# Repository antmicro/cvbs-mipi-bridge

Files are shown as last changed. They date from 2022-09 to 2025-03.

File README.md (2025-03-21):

# Composite Video (CVBS) to MIPI CSI-2 bridge

Copyright (c) 2022-2025 [Antmicro](https://www.antmicro.com)



Baseboard visualization

## Overview

This repository contains open hardware design files for a video bridge converting the analog composite video (CBVS) standard into MIPI CSI-2.
The video conversion is handled with Analog Devices [ADV7828-M](https://www.analog.com/media/en/technical-documentation/data-sheets/ADV7282.pdf) 10-bit 4x Oversampled SDTV Video Decoder.
The design files were prepared in KiCad.

## Repository structure

The main repository directory contains KiCad PCB project files, a LICENSE and README.
The remaining files are stored in the following directories:

* `lib` - contains the component libraries
* `img` - contains graphics for this README
* `doc` - contains pdf schematics
* `assets` - contains visual assets for showcasing this design on [Open Hardware Portal](https://openhardware.antmicro.com)

## Key Features

* Analog Devices ADV7282-M CVBS-to-MIPI video converter
* 4 analog video input channels exposed on RCA connectors
* A single 1-lane MIPI CSI-2 digital output interface

Please note that according to the datasheet the ADV7282-M includes an embedded analog multiplexer and processes only one analog input channel at a time.

This video accessory is electrically compatible with several video processing platforms created by Antmicro, such as:
 
* [Jetson Nano Baseboard](https://github.com/antmicro/jetson-nano-baseboard) supporting NVIDIA Jetson Nano, Jetson Xavier NX, Jetson TX2 NX
* [Google Coral Baseboard](https://github.com/antmicro/google-coral-baseboard)
* [Snapdragon 625 Baseboard](https://github.com/antmicro/snapdragon-625-baseboard)
* [Snapdragon 845 Baseboard](https://github.com/antmicro/snapdragon-845-baseboard)
* [AMD-Xilinx Kria K26 DevBoard](https://github.com/antmicro/kria-k26-devboard)

It can also be used with NVIDIA AGX Xavier and NVIDIA AGX Orin with a dedicated [adapter](https://github.com/antmicro/jetson-agx-csi-adapter).

## Board diagram

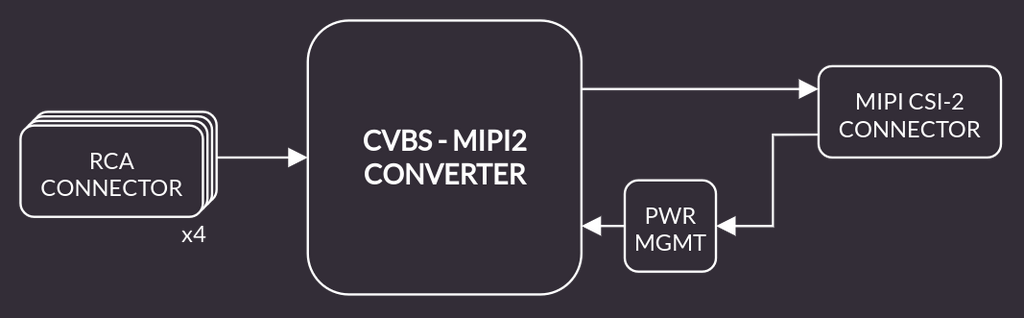
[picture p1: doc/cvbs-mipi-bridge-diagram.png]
Diagram


## License

[Apache-2.0](LICENSE)

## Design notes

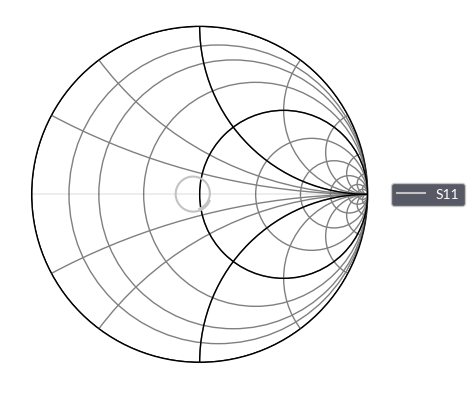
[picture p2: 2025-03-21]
assets/si/AIN1_ESD/S_11_smith.png

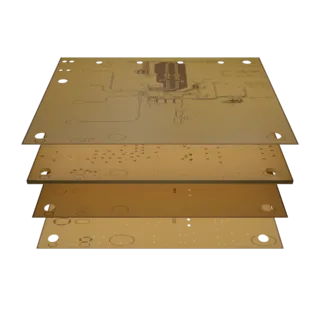
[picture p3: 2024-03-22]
assets/previews/layer1_thumbnail.webp

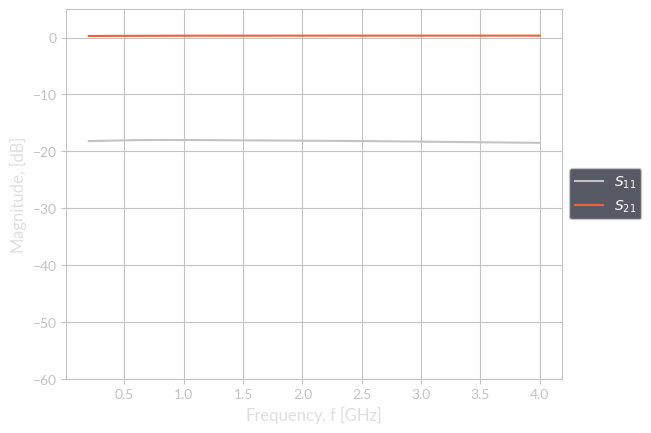
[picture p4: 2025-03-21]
assets/si/AIN2/S_x1.png

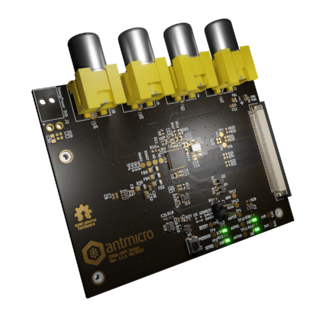
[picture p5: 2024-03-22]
assets/previews/leftT_thumbnail.png

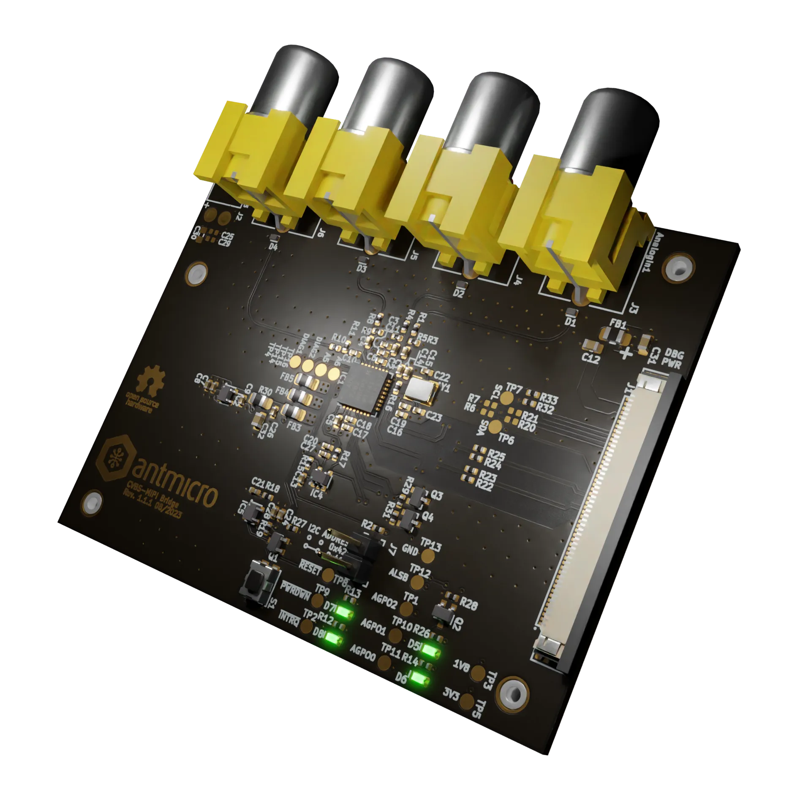
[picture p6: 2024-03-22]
assets/previews/rightT.webp

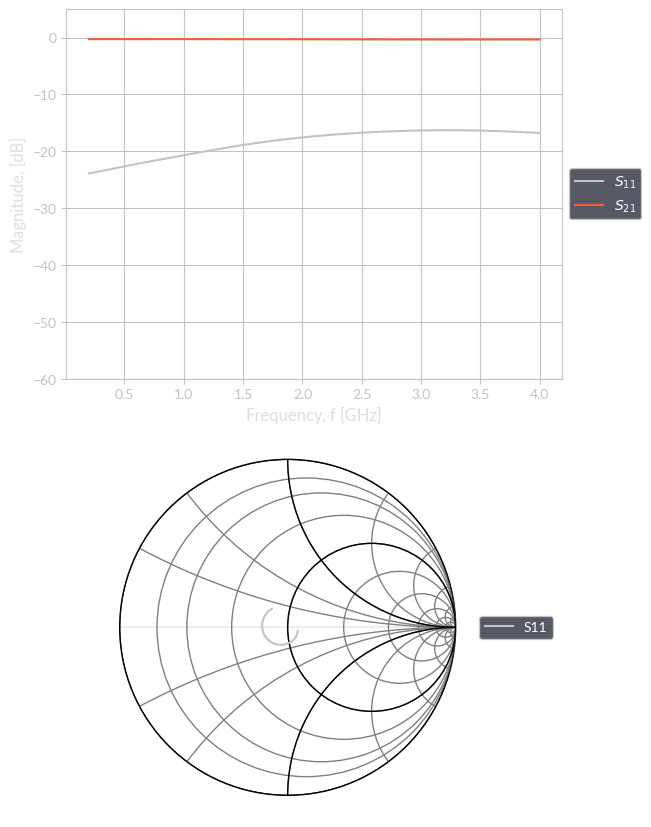
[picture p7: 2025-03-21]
assets/si/AIN2_ESD/s_param_and_smith_1.png

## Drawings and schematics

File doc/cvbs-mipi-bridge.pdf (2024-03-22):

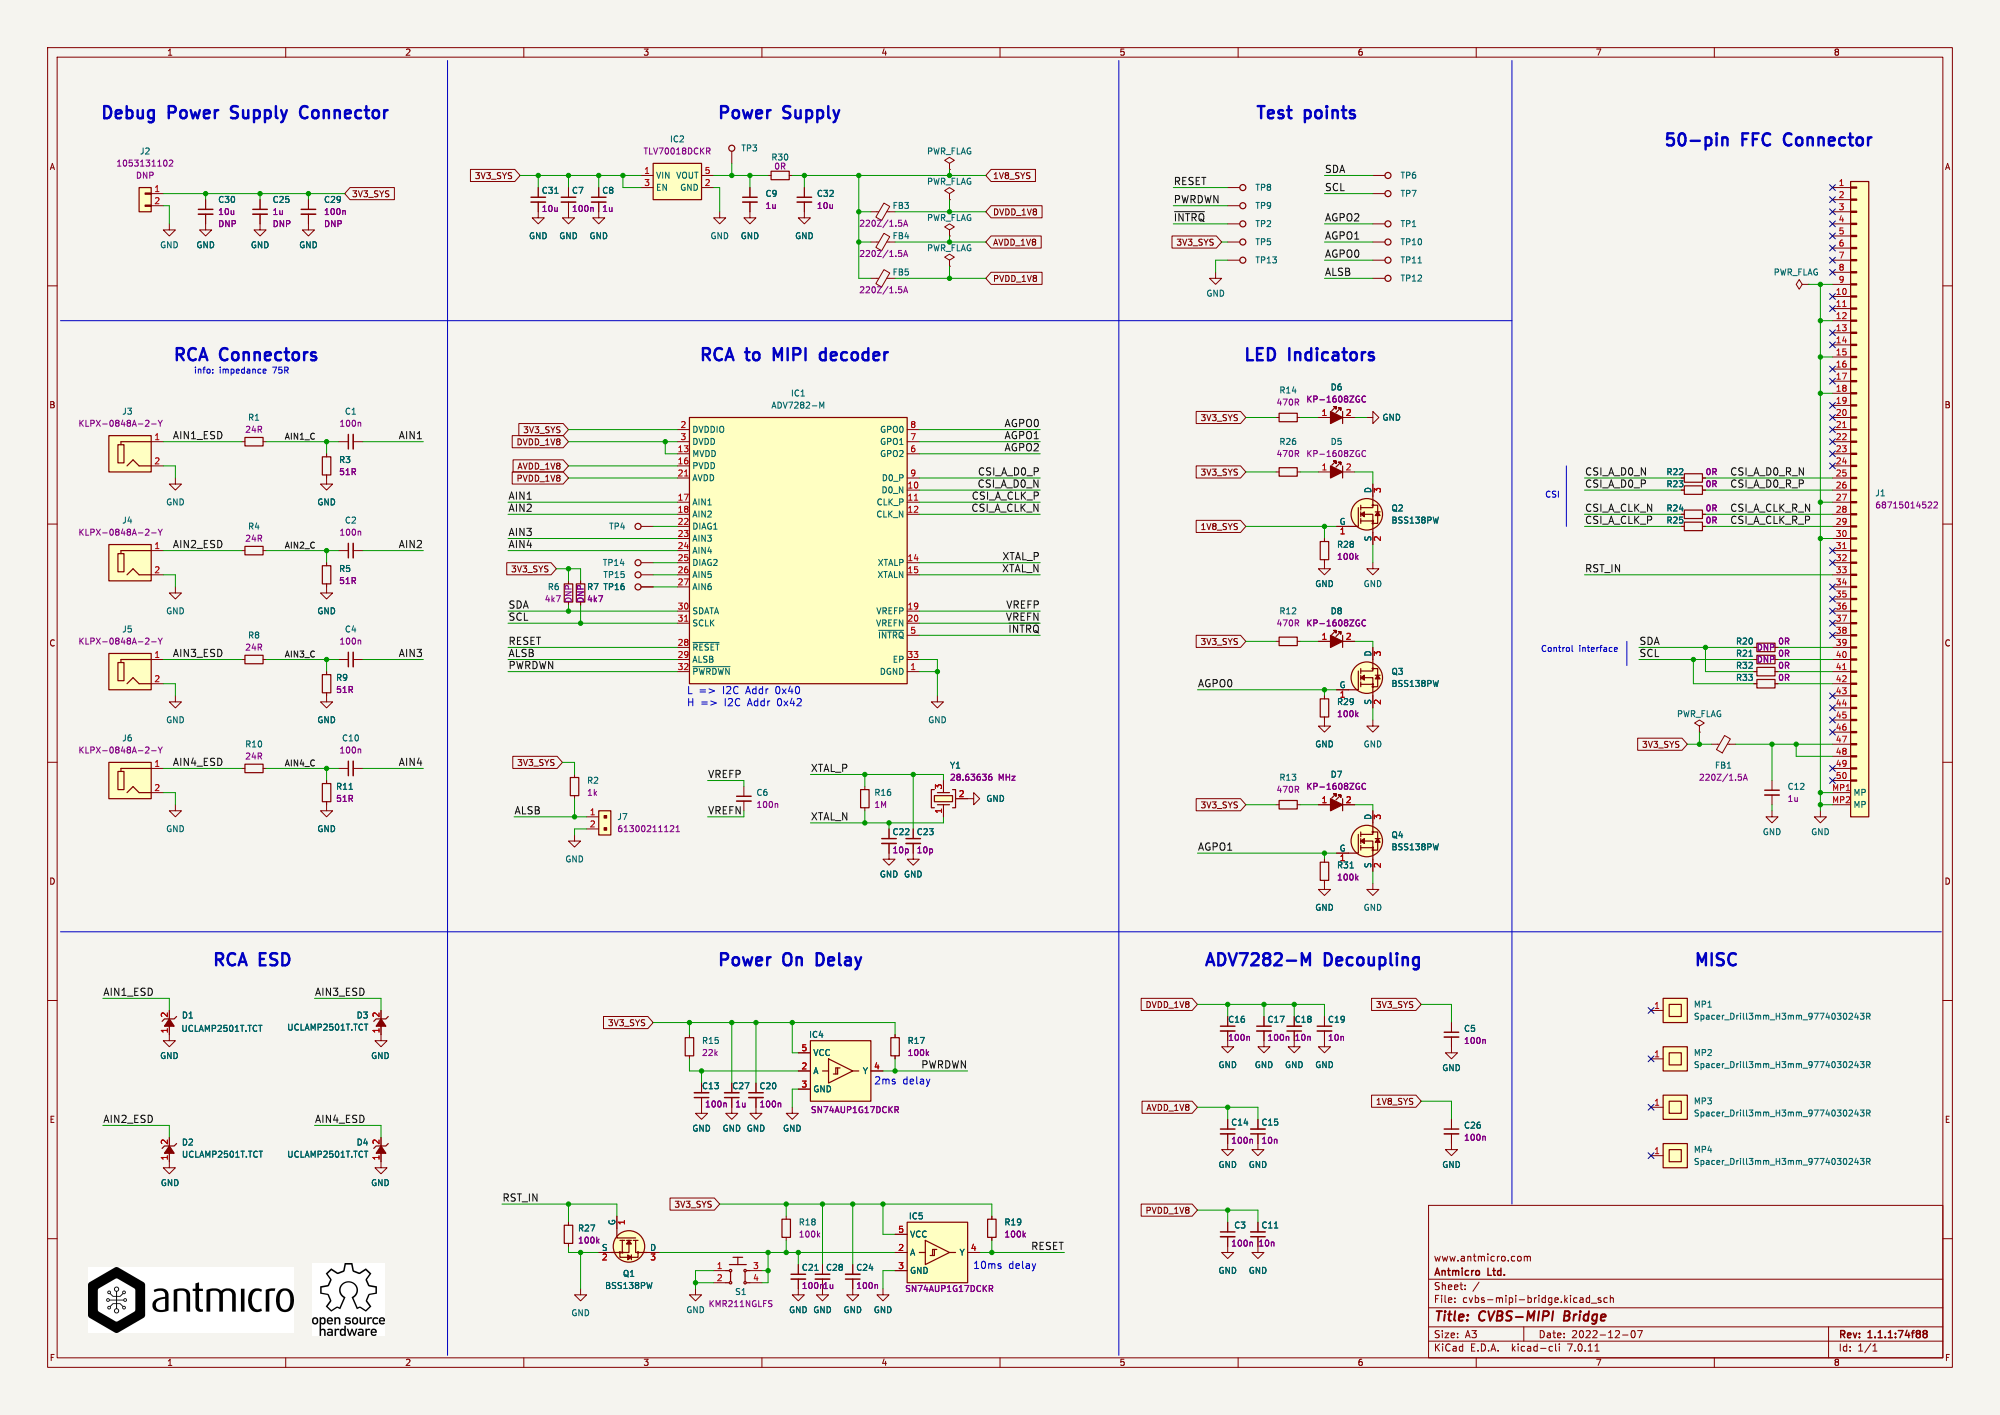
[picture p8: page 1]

CSI Debug Power Supply Connector

Id: 1/1 Title: CVBS-MIPI Bridge

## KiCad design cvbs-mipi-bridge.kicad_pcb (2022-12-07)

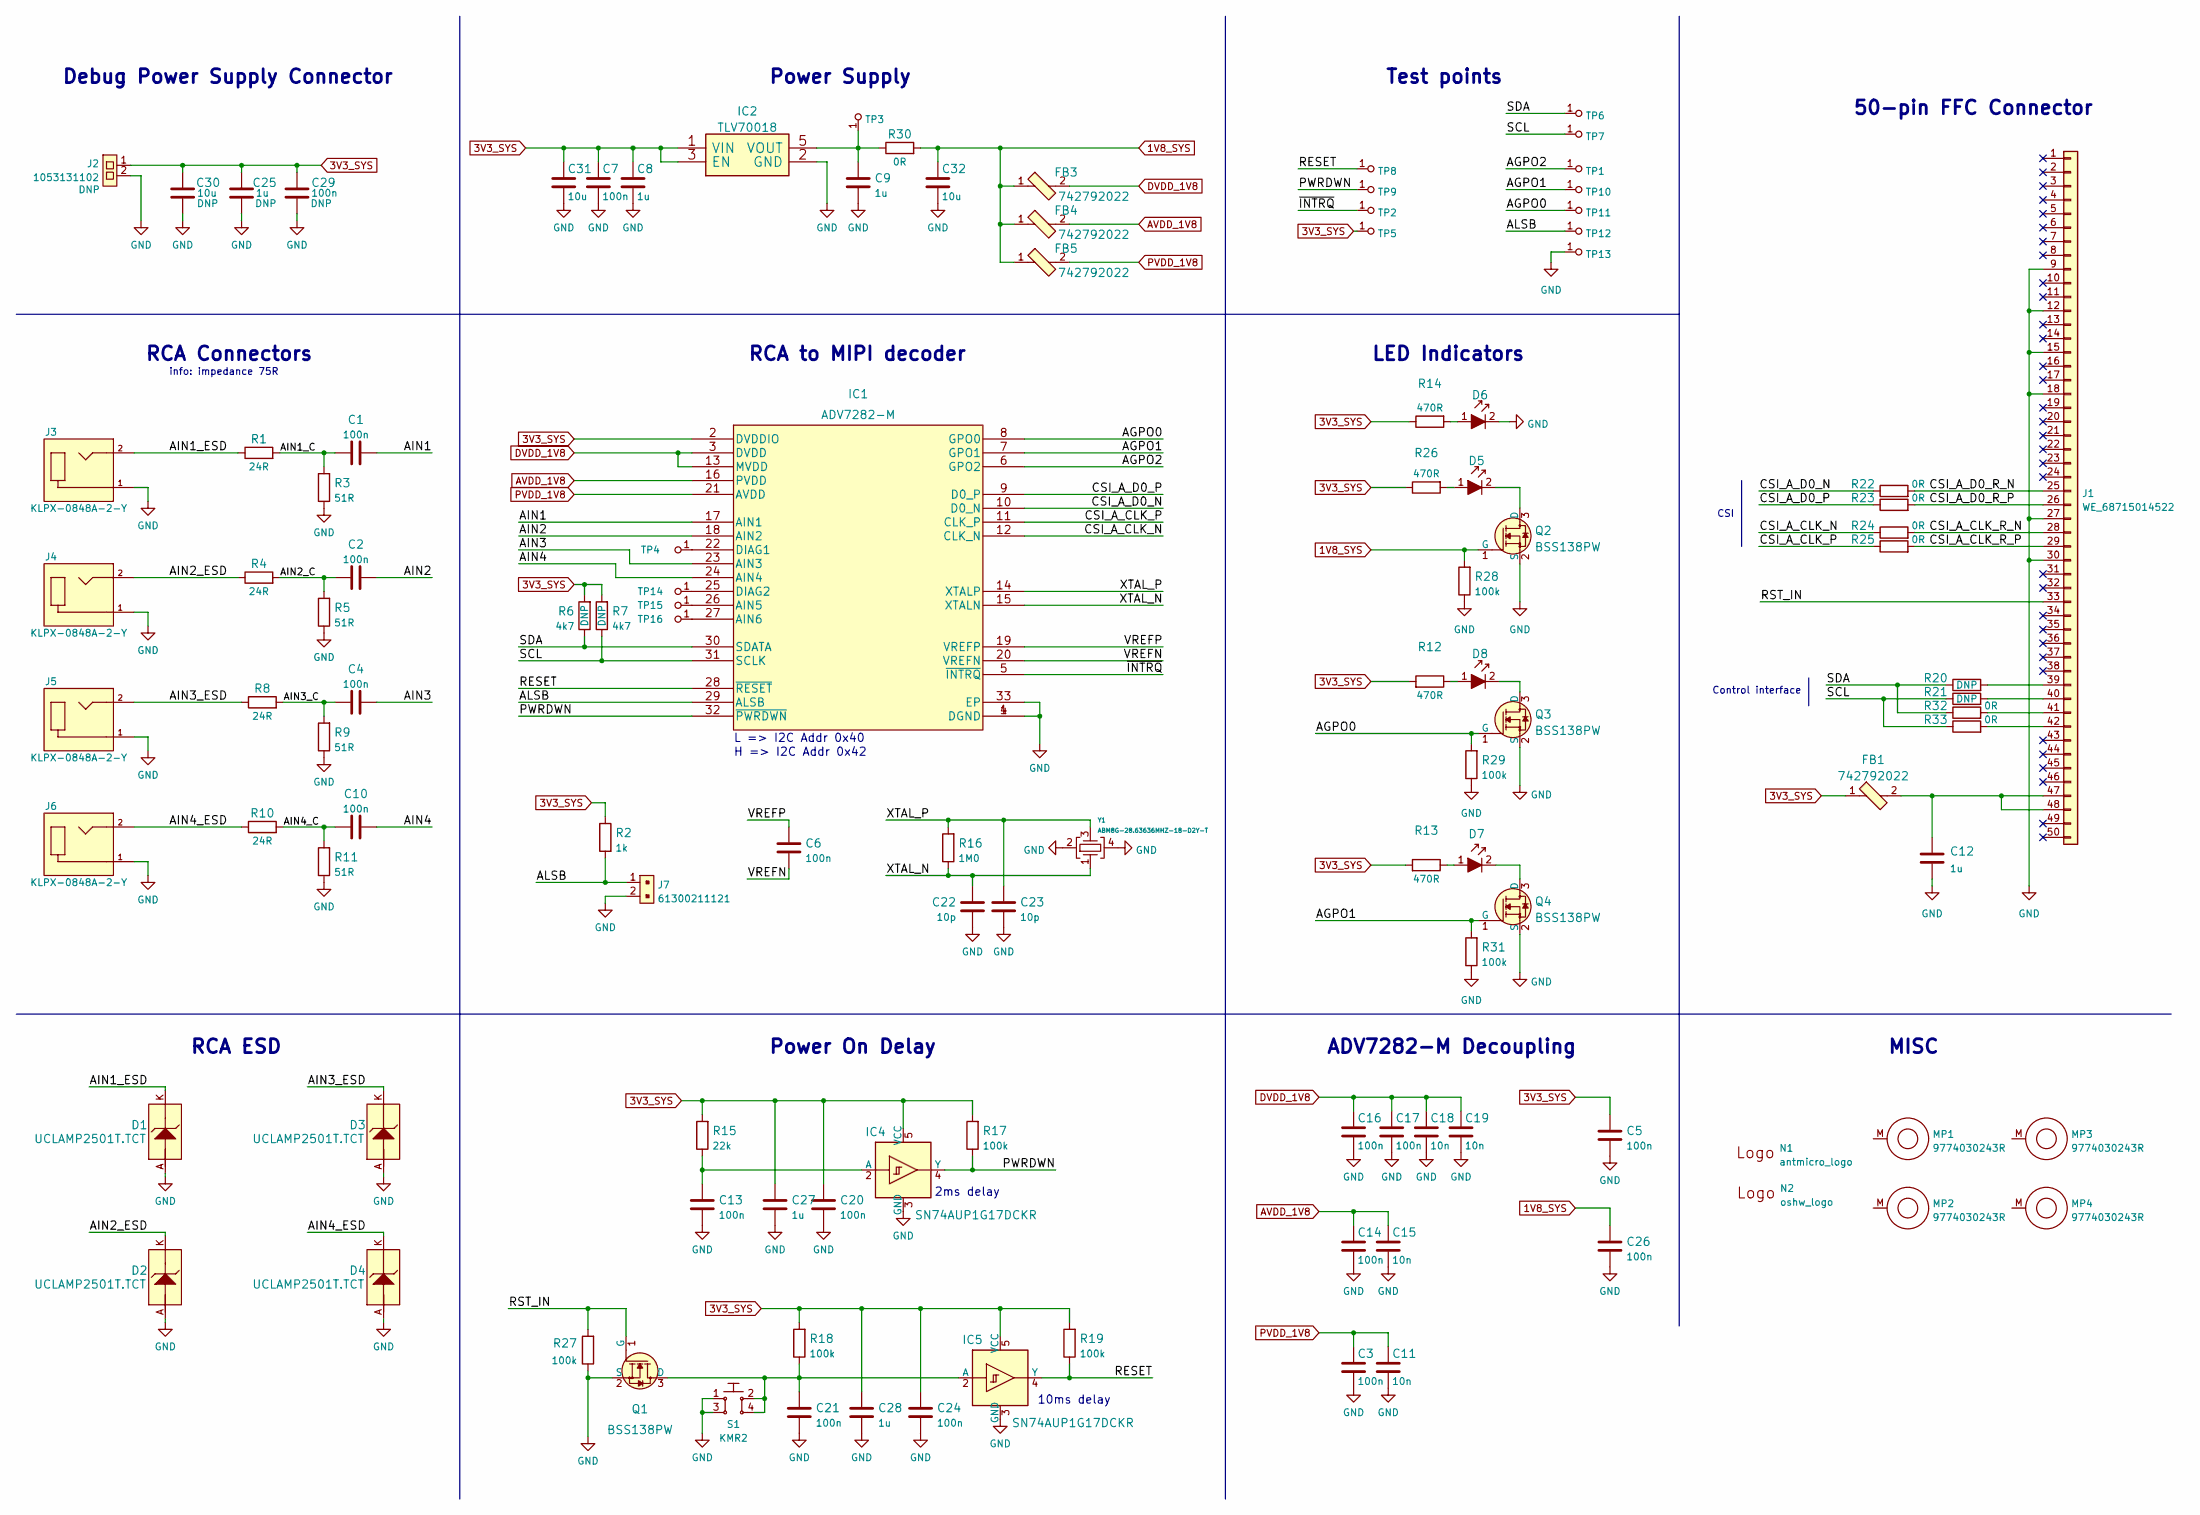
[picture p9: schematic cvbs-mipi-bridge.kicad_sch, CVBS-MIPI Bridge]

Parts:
C1, C2, C3, C4, C5, C6, C7, C10, C14, C16, C17, C26, C29: C_100n_0402; 0402-cap; MPN GRM155R61H104KE14D
C8, C9, C25: C_1u_0402; 0402-cap; MPN C1005X6S1A105K050BC
C11, C15, C18, C19: C_10n_0402; 0402-cap; MPN 04025G103ZAT2A
C12: C_1u_0603; 0603-cap; MPN 0603YD105KAT2A
C13, C20, C21, C24: C_100n_0402; 0402-cap_ThermalReliefs_ZoneSizeSettings; MPN GRM155R61H104KE14D
C22, C23: C_10p_0402; 0402-cap; MPN MC0402N100D500CT
C27, C28: C_1u_0402; 0402-cap_ThermalReliefs_ZoneSizeSettings; MPN C1005X6S1A105K050BC
C30, C31, C32: C_10u_0603; 0603-cap; MPN GRM188R61A106KE69D
D1, D2, D3, D4: UCLAMP2501T.TCT; SLP1006P2T; MPN UCLAMP2501T.TCT
D5, D7, D8: KP-1608ZGC; LED_0603; MPN KP-1608EC
D6: KP-1608ZGC; LED_0603_ThermalReliefs_ZoneSizeSettings; MPN KP-1608EC
FB1, FB3, FB4, FB5: 742792022; 0805-res; MPN 742792022
IC1: ADV7282-M; LFCSP-32-1EP-5x5mm; MPN ADV7282WBCPZ-M
IC2: TLV70018; SC-70-5; MPN TLV70018DCKR
IC4, IC5: SN74AUP1G17DCKR; SC-70-5; MPN SN74AUP1G17DCKR
J1: WE_68715014522; MPN 68715014522
J2: 1053131102; MPN 1053131102
J3, J4, J5, J6: KLPX-0848A-2-Y; MPN KLPX-0848A-2-Y
J7: 61300211121; PinHeader_1x2_P2.54_Drill0.9mm; MPN 61300211121
MP1, MP2, MP3, MP4: 9774030243R; MPN 9774030243R
N1: antmicro_logo; antmicro-logo_scaled_20mm_mask
N2: oshw_logo; oshw-logo
Q1, Q2, Q3, Q4: BSS138PW; SC70-3; MPN BSS138PW
R1, R4, R8, R10: R_24R_0402; 0402-res; MPN ERJ-2RKF24R0X
R2: R_1k_0402; 0402-res; MPN CR0402-FX-1001GLF
R3, R5, R9, R11: R_51R_0402; 0402-res; MPN RC0402FR-0751RL
R6, R7: R_4k7_0402; 0402-res; MPN MCS04020C4701FE000
R12, R13, R14, R26: R_470R_0402; 0402-res; MPN CRCW0402470RFKED
R15: R_22k_0402; 0402-res; MPN ERJ-2RKF2202X
R16: R_1M0_0402; 0402-res; MPN CRG0402F1M0
R17, R18, R19: R_100k_0402; 0402-res; MPN CRCW0402100KFKEDHP
R20, R21, R22, R23, R24, R25, R32, R33: R_0R_0402; 0402-res; MPN ERJ2GE0R00X
R27, R28, R29, R31: R_100k_0402; 0402-res_ThermalReliefs_ZoneSizeSettings; MPN CRCW0402100KFKEDHP
R30: R_0R_0805; 0805-res; MPN CRCW08050000Z0EA
S1: KMR2; SW_SPST_4.2x2.8_ThermalReliefs_ZoneSizeSettings; MPN KMR211NGLFS
TP1, TP2, TP3, TP4, TP5, TP6, TP7, TP8, TP9, TP10, TP11, TP12, TP13, TP14, TP15, TP16: TP; TP-R-1.5
Y1: ABM8G-28.63636MHZ-18-D2Y-T; KX-7; MPN ABM8G-25.000MHZ-18-D2Y-T

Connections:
1V8_SYS: C26.2, C32.1, FB3.1, FB4.1, FB5.1, Q2.1 (G), R28.2, R30.2
3V3_SYS: C5.2, C7.2, C8.1, C20.1, C24.1, C25.1, C27.1, C28.1, C29.2, C30.1, C31.1, FB1.1, IC1.2 (DVDDIO), IC2.1 (VIN), IC2.3 (EN), IC4.5 (VCC), IC5.5 (VCC), J2.1, R2.1, R6.2, R7.2, R12.2, R13.2, R14.1, R15.2, R17.2, R18.2, R19.2, R26.1, TP5.1
/AGPO0: IC1.8 (GPO0), Q3.1 (G), R29.2, TP11.1
/AGPO1: IC1.7 (GPO1), Q4.1 (G), R31.2, TP10.1
/AGPO2: IC1.6 (GPO2), TP1.1
/AIN1: C1.2, IC1.17 (AIN1)
/AIN1_C: C1.1, R1.2, R3.2
/AIN1_ESD: D1.K, J3.2, R1.1
/AIN2: C2.2, IC1.18 (AIN2)
/AIN2_C: C2.1, R4.2, R5.2
/AIN2_ESD: D2.K, J4.2, R4.1
/AIN3: C4.2, IC1.23 (AIN3)
/AIN3_C: C4.1, R8.2, R9.2
/AIN3_ESD: D3.K, J5.2, R8.1
/AIN4: C10.2, IC1.24 (AIN4)
/AIN4_C: C10.1, R10.2, R11.2
/AIN4_ESD: D4.K, J6.2, R10.1
/ALSB: IC1.29 (ALSB), J7.1, R2.2, TP12.1
/CSI_A_CLK_N: IC1.12 (CLK_N), R24.1
/CSI_A_CLK_P: IC1.11 (CLK_P), R25.1
/CSI_A_CLK_R_N: J1.28, R24.2
/CSI_A_CLK_R_P: J1.29, R25.2
/CSI_A_D0_N: IC1.10 (D0_N), R22.1
/CSI_A_D0_P: IC1.9 (D0_P), R23.1
/CSI_A_D0_R_N: J1.25, R22.2
/CSI_A_D0_R_P: J1.26, R23.2
/PWRDWN: IC1.32 (~PWRDWN), IC4.4 (Y), R17.1, TP9.1
/RESET: IC1.28 (~RESET), IC5.4 (Y), R19.1, TP8.1
/RST_IN: J1.33, Q1.1 (G), R27.2
/SCL: IC1.31 (SCLK), R7.1, R21.1, R33.1, TP7.1
/SDA: IC1.30 (SDATA), R6.1, R20.1, R32.1, TP6.1
/VREFN: C6.1, IC1.20 (VREFN)
/VREFP: C6.2, IC1.19 (VREFP)
/XTAL_N: C22.1, IC1.15 (XTALN), R16.1, Y1.1
/XTAL_P: C23.1, IC1.14 (XTALP), R16.2, Y1.3
/~INTRQ: IC1.5 (~INTRQ), TP2.1
AVDD_1V8: C14.2, C15.1, FB4.2, IC1.16 (PVDD)
DVDD_1V8: C16.2, C17.2, C18.1, C19.1, FB3.2, IC1.3 (DVDD), IC1.13 (MVDD)
GND: C3.1, C5.1, C7.1, C8.2, C9.2, C11.2, C12.2, C13.2, C14.1, C15.2, C16.1, C17.1, C18.2, C19.2, C20.2, C21.2, C22.2, C23.2, C24.2, C25.2, C26.1, C27.2, C28.2, C29.1, C30.2, C31.2, C32.2, D1.A, D2.A, D3.A, D4.A, D6.2, IC1.1 (DGND), IC1.4 (DGND), IC1.33 (EP), IC2.2 (GND), IC4.3 (GND), IC5.3 (GND), J1.9, J1.12, J1.15, J1.18, J1.27, J1.30, J2.2, J3.1, J4.1, J5.1, J6.1, J7.2, Q1.2 (S), Q2.2 (S), Q3.2 (S), Q4.2 (S), R3.1, R5.1, R9.1, R11.1, R27.1, R28.1, R29.1, R31.1, S1.1, S1.3, TP13.1, Y1.2, Y1.4
unnamed: C9.1, IC2.5 (VOUT), R30.1, TP3.1
unnamed: C12.1, FB1.2, J1.47, J1.48
unnamed: C13.1, IC4.2 (A), R15.1
unnamed: C21.1, IC5.2 (A), Q1.3 (D), R18.1, S1.2, S1.4
unnamed: D5.1, R26.2
unnamed: D5.2, Q2.3 (D)
unnamed: D6.1, R14.2
unnamed: D7.1, R13.1
unnamed: D7.2, Q4.3 (D)
unnamed: D8.1, R12.1
unnamed: D8.2, Q3.3 (D)
unnamed: IC1.22 (DIAG1), TP4.1
unnamed: IC1.25 (DIAG2), TP14.1
unnamed: IC1.26 (AIN5), TP15.1
unnamed: IC1.27 (AIN6), TP16.1
unnamed: J1.39, R20.2
unnamed: J1.40, R21.2
unnamed: J1.41, R32.2
unnamed: J1.42, R33.2
PVDD_1V8: C3.2, C11.1, FB5.2, IC1.21 (AVDD)

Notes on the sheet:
10ms delay
50-pin FFC Connector
MISC
Debug Power Supply Connector
LED Indicators
Power Supply
Power On Delay
L => I2C Addr 0x40
ADV7282-M Decoupling
CSI
RCA to MIPI decoder
info: impedance 75R
Test points
RCA Connectors
H => I2C Addr 0x42
2ms delay
Control interface
RCA ESD

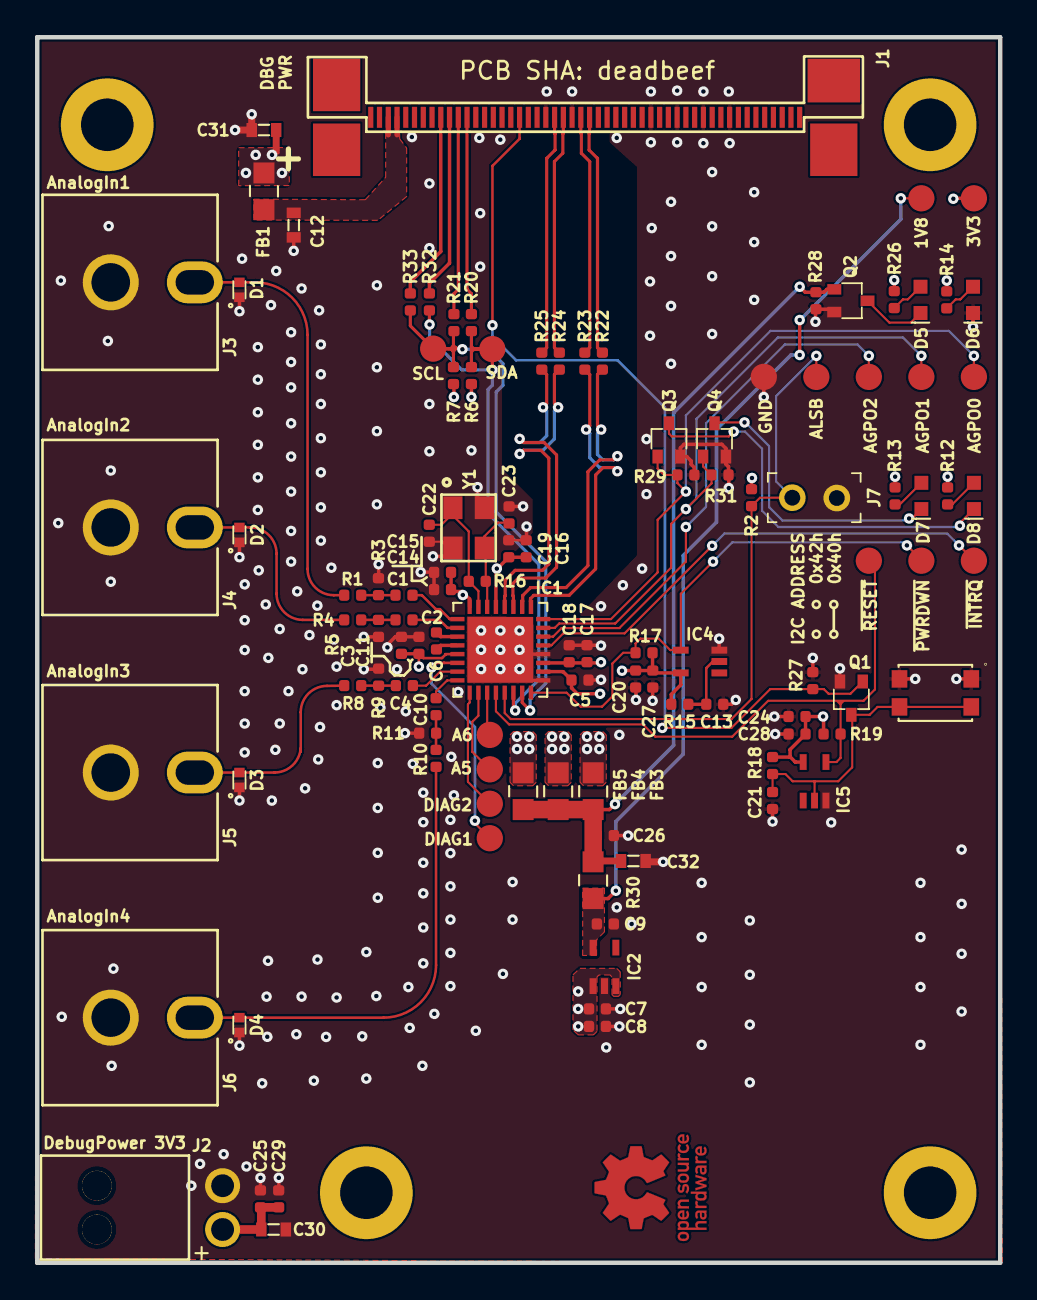
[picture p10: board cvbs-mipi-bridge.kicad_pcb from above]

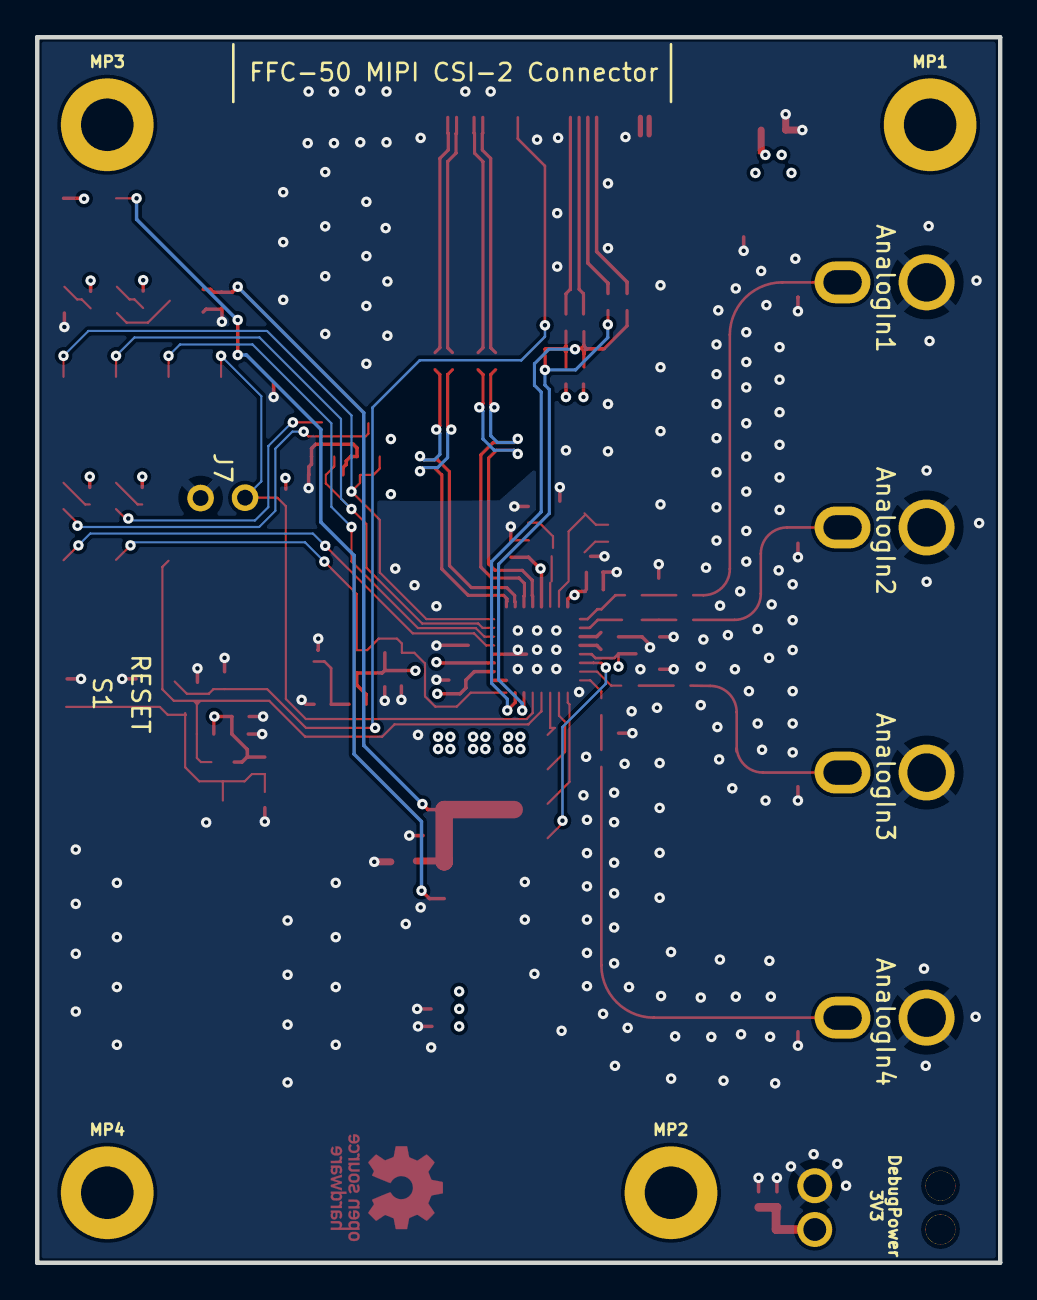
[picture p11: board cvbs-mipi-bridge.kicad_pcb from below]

Board: 4 copper layers, 55.0 x 70.0 mm, 116 parts (4 on the bottom side), 59 nets.

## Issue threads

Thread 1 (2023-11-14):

[QUESTION] Where can we got the software for that project?

o-murphy, 2023-11-14:

petergonzalez8585, 2025-06-06:
hi, i made this board and career board according the antmicro jetson nano design, and all the peripheral of career board work fine and we boot to system but at now we are unable to handle driver to add vide0 and video1 to capture the video using gstreamer, please help how to overcome the software of this project, thanks

pgielda, 2025-06-09:
Its not really an issue with the board. The board has an Analog Devices chip, you can find the datasheet here: https://www.analog.com/media/en/technical-documentation/data-sheets/ADV7282.pdf

petergonzalez8585, 2025-06-09:
> Its not really an issue with the board. The board has an Analog Devices chip, you can find the datasheet here: https://www.analog.com/media/en/technical-documentation/data-sheets/ADV7282.pdf

hi sir, thanks very much for reply, I also sure the board and the hardware is ok, but my problem is that i cannot add diver to kernel for this hardware and there is no any help for this job in the ant micro site and and also clear way to perform this sequence i would be so thanks if you can help send a manual to do this
peter.gonzalez8585@gmail.com

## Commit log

2022-09-06 Initial commit, add Altium Design Files
    [BOM-Suplliers-mod_ADV7280-M.xlsx, BOM-mod_ADV7280-M.xlsx, decoder.PcbDoc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]
2022-09-07 Initial convertion commit. Changed Outputs to Altium-Outputs
    [BOM-Suplliers-mod_ADV7280-M.xlsx, BOM-mod_ADV7280-M.xlsx, antmicro-cvbs-mipi-bridge.kicad_pcb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]
2022-09-07 Moved Altium project legacy files into separate folder
    [decoder.PcbDoc, decoder.SchDoc, mod_ADV7280-M.PrjPcb]
2022-09-07 Started converting schematics to antmicro-kicad-library
    [antmicro-cvbs-mipi-bridge.kicad_sch]
2022-09-08 Finished correcting schematics
    [antmicro-cvbs-mipi-bridge.kicad_sch]
2022-09-08 Reordered components on schematic. Bumped revision to 1.2.0
    [antmicro-cvbs-mipi-bridge.kicad_sch]
2022-09-08 Defined net classes
    [antmicro-cvbs-mipi-bridge.kicad_pcb]
2022-09-08 Started component positions adjusment and placement
    [antmicro-cvbs-mipi-bridge.kicad_pcb, antmicro-cvbs-mipi-bridge.kicad_sch]
2022-09-09 Finished placement. Removed 5V net and components. Started routing
    [antmicro-cvbs-mipi-bridge.kicad_pcb, antmicro-cvbs-mipi-bridge.kicad_sch]
2022-09-12 Finished and optimized routing on PCB
    [antmicro-cvbs-mipi-bridge.kicad_pcb]
2022-09-12 Schematic review fixes
    [antmicro-cvbs-mipi-bridge.kicad_sch]
2022-09-12 Fixes adjusted visually. New components annotated
    [antmicro-cvbs-mipi-bridge.kicad_sch]
2022-09-14 Corrected PCB after review
    [antmicro-cvbs-mipi-bridge.kicad_pcb]
2022-09-14 loclib. Added new components from schematic after review
    [antmicro-cvbs-mipi-bridge.kicad_pcb, antmicro-cvbs-mipi-bridge.kicad_sch]
2022-09-14 Corrected ADV7280 footprint. Finished corrections and optimizations. Added missing step model
    [antmicro-cvbs-mipi-bridge.kicad_pcb, antmicro-cvbs-mipi-bridge.kicad_sch]
2022-09-29 Replace RCA connectors
    [cvbs-mipi-bridge.kicad_pcb, cvbs-mipi-bridge.kicad_sch]
2022-09-29 Replace TVS diodes
    [cvbs-mipi-bridge.kicad_pcb, cvbs-mipi-bridge.kicad_sch]
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2022-09-29 Place components, route video signals
    [cvbs-mipi-bridge.kicad_pcb, cvbs-mipi-bridge.kicad_sch]
2022-09-29 Replace DC power connector
    [cvbs-mipi-bridge.kicad_pcb, cvbs-mipi-bridge.kicad_sch]
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2022-09-29 Chip replaced with ADV7282-M
    [cvbs-mipi-bridge.kicad_sch]
2022-09-29 Update naming convention, assign revision 1.0.0, update signage on PCB
    [cvbs-mipi-bridge.kicad_pcb, cvbs-mipi-bridge.kicad_sch]
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2022-09-29 Connected GNDs, cleaned DRC
    [cvbs-mipi-bridge.kicad_pcb]
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2022-10-12 Mark C30 as DNP, improve it's clarity on schematic
    [cvbs-mipi-bridge.kicad_sch]
2022-12-07 PCB: Clean up doubled IC1 reference designator on F.Silkscreen
    [cvbs-mipi-bridge.kicad_pcb]
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2022-12-07 Update SN74AUP1G17DCKR symbol on SCH from local library
    [cvbs-mipi-bridge.kicad_pcb, cvbs-mipi-bridge.kicad_sch]
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2022-12-07 Update Q1-Q4 from global library on SCH and PCB
    [cvbs-mipi-bridge.kicad_pcb, cvbs-mipi-bridge.kicad_sch]
2022-12-07 Reroute tracks after updating IC4, IC5, Q1-4 footprint
    [cvbs-mipi-bridge.kicad_pcb]
2022-12-07 PCB: Fix DRC errors & warnings
    - Move GND Via near C10 & C4, which collided with PVDD_1V8 power line on In2.Cu layer
    - Move Q1-Q4, IC2-5 Reference Designators around on F. Silkscreen
    [cvbs-mipi-bridge.kicad_pcb]
2022-12-07 PCB: Move Reference Designators clipped by un-tented vias
    [cvbs-mipi-bridge.kicad_pcb]
2022-12-07 Increase revision number to 1.0.1 - update title blocks & PCB marking
    [cvbs-mipi-bridge.kicad_pcb, cvbs-mipi-bridge.kicad_sch]
2022-12-07 Correct F.Cu's main GND Copper Zone's minimal clearance and width to Eurocircuits Pattern Class 7
    [cvbs-mipi-bridge.kicad_pcb]
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2022-12-07 Add thermal relief versions of 0402 passives' footprints, fix metadata
    - Fixed Description, Value and Keywords for 0402-cap (it was described as a Resistor)
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2022-12-07 Make thermal-relief versions of two-lead footprints in project lib
    These are with Thermal Relief Spoke Width & Gap Clearance inherited from Copper Zone settings
2022-12-07 Change F.Cu's GND plane thermal relief sizes to 0.125mm clearance, 0.2mm spoke width
    [cvbs-mipi-bridge.kicad_pcb]
2022-12-07 SCH: Change selected Power On Delay elements' footprints to thermal-relief variants
    Thermal reliefs added to: R27, C13, C20, C21, C24, C27, C28
    [cvbs-mipi-bridge.kicad_sch]
2022-12-07 SCH: Change selected LED Indicators' section elements to thermal-relief variatns
    These are: D6, R28, R29, R31
    [cvbs-mipi-bridge.kicad_sch]
2022-12-07 Update PCB from SCH after changing selected symbols' footprints
    [cvbs-mipi-bridge.kicad_pcb]
2022-12-07 Refill copper zones after PCB update
    [cvbs-mipi-bridge.kicad_pcb]
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2022-12-07 Make 3V3_SYS power tracks between IC1,IC4,IC5 use Net-class width (0.2mm)
    - 3V3_SYS Track width increased from 0.125 mm to 0.2mm, zones re-filled
    - Re-routed some tracks for improved aesthetics and optimised thermal reliefs
    [cvbs-mipi-bridge.kicad_pcb]
2022-12-07 Change S1 footprint to thermal-relief version
    [cvbs-mipi-bridge.kicad_pcb, cvbs-mipi-bridge.kicad_sch]
2022-12-07 Tidy up DVDD_1V8 track near IC1 pin 3
    - Re-route with a single straight track
    - Increase track width to 0.2mm, like on other power-rails
    [cvbs-mipi-bridge.kicad_pcb]
2022-12-07 Fix/improve F.Silkscreen, adjust 2 GND vias to fit
    [cvbs-mipi-bridge.kicad_pcb]
2022-12-07 Uniformize F.Silkscreen text to 0.65mm size, 0.15mm thickness; adjust position where needed
    [cvbs-mipi-bridge.kicad_pcb]
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2022-12-07 Board Setup: Change soldermask, silkscreen and copper plating to prototype's colors.
    [cvbs-mipi-bridge.kicad_pcb]
2022-12-07 Improve F. Silkscreen, fine-tune board/soldermask color for KiCad 3D Viewer
    [cvbs-mipi-bridge.kicad_pcb]
2022-12-07 Fix DRC errors: LED RefDes's moved, 3V3_SYS track near C20 rerouted
    [cvbs-mipi-bridge.kicad_pcb]
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2022-12-07 Add connectors & button descriptions to B.Silkscreen
    [cvbs-mipi-bridge.kicad_pcb]
2022-12-07 SCH: Cosmetic improvements
    - Add labels for AGPO2 and ~INTRQ
    - Move their Test Points to "Test points" section
    - Rearrange "Test points" section to somewhat resemble actual test point placement on PCB
    - Uniformize local label font size to 1.524 mm, except for AIN nets in RCA Connectors section
    [cvbs-mipi-bridge.kicad_sch]
2022-12-07 Update PCB nets from SCH
    [cvbs-mipi-bridge.kicad_pcb]
2022-12-07 Update antmicro_logo footprint reference to correct one
    Update in local library, then on SCH, then updated PCB from SCH
    [cvbs-mipi-bridge.kicad_pcb, cvbs-mipi-bridge.kicad_sch]
2022-12-07 Increase design revision number to 1.0.2 - update title blocks and date
    [cvbs-mipi-bridge.kicad_pcb, cvbs-mipi-bridge.kicad_sch]
2022-12-07 Add second pair of resistors for re-connecting I2C.
    [cvbs-mipi-bridge.kicad_pcb, cvbs-mipi-bridge.kicad_sch]
2022-12-07 Bump PCB revision to 1.2.0
    [cvbs-mipi-bridge.kicad_pcb, cvbs-mipi-bridge.kicad_sch]
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2023-10-13 [#50306] Add OHP assets and schematic PDF
    [stackup.csv]
2024-03-20 [#56797] Fix lib references
    [cvbs-mipi-bridge.kicad_sch]
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2024-03-26 [#56797] Update revision & date
    [cvbs-mipi-bridge.kicad_sch]
2024-03-28 [#56797] Mark components DNP
    [cvbs-mipi-bridge.kicad_sch]
